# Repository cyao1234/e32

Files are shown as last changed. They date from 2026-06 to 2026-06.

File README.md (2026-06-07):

# ESP32-s2 development board

With drunk components!

---



This is a single board esp32-s2 development board. with two neopixels and an on-board antenna.

It has drunk component placement and some nice freeform traces

The 2.54mm pitch can be fitten in breadboard and used nicely with jumpers

The programming can be done over USB-C ports

---



The scehmatic is easy and simple, giving people the maximum leverage.

Everything is impedance matched, giving the best EMC and high-speed SI performance

---

For bom see `bom.csv`

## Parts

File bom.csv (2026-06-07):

What | $$$ | Where
PCB | $82.32 | JLCPCB
Components | $39.24 | lcsc

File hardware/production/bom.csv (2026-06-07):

Designator | Footprint | Quantity | Value | LCSC Part #
C1, C2 | 0402 | 2 | 33pF | C5137486
C10 | 0402 | 1 | 100nF | C1525
C3, C4, C5, C6, C7, C8, C9 | 0402 | 7 | 1uF | C52923
C39, C40 | 0402 | 2 | 4.7uF | C23733
D1, D2 | LED_WS2812B-2020_PLCC4_2.0x2.0mm | 2 | WS2812B-2020 | C5349955
F1 | 0805 | 1 | Fuse
J1 | USB_C_Receptacle_HRO_TYPE-C-31-M-12 | 1 | USB_C_Receptacle_USB2.0_14P | C165948
J5, J6 | PinHeader_1x15_P2.54mm_Vertical | 2 | Conn_01x15
R1, R2, R3, R4, R5 | 0402 | 5 | 5.1k | C25905
R6, R7, R8 | 0402 | 3 | 10k | C25744
SW1 | switch_button_TS-1088-AR02016 | 1 | SW_Push | C720477
U1 | QFN-56-1EP_7x7mm_P0.4mm_EP4x4mm_ThermalVias | 1 | ESP32-S2 | C2840995
U2 | SOT-23-3 | 1 | XC6206PxxxMR | C5446
Y1 | Crystal_SMD_2016-4Pin_2.0x1.6mm | 1 | 25MHz 20pF | C37635326

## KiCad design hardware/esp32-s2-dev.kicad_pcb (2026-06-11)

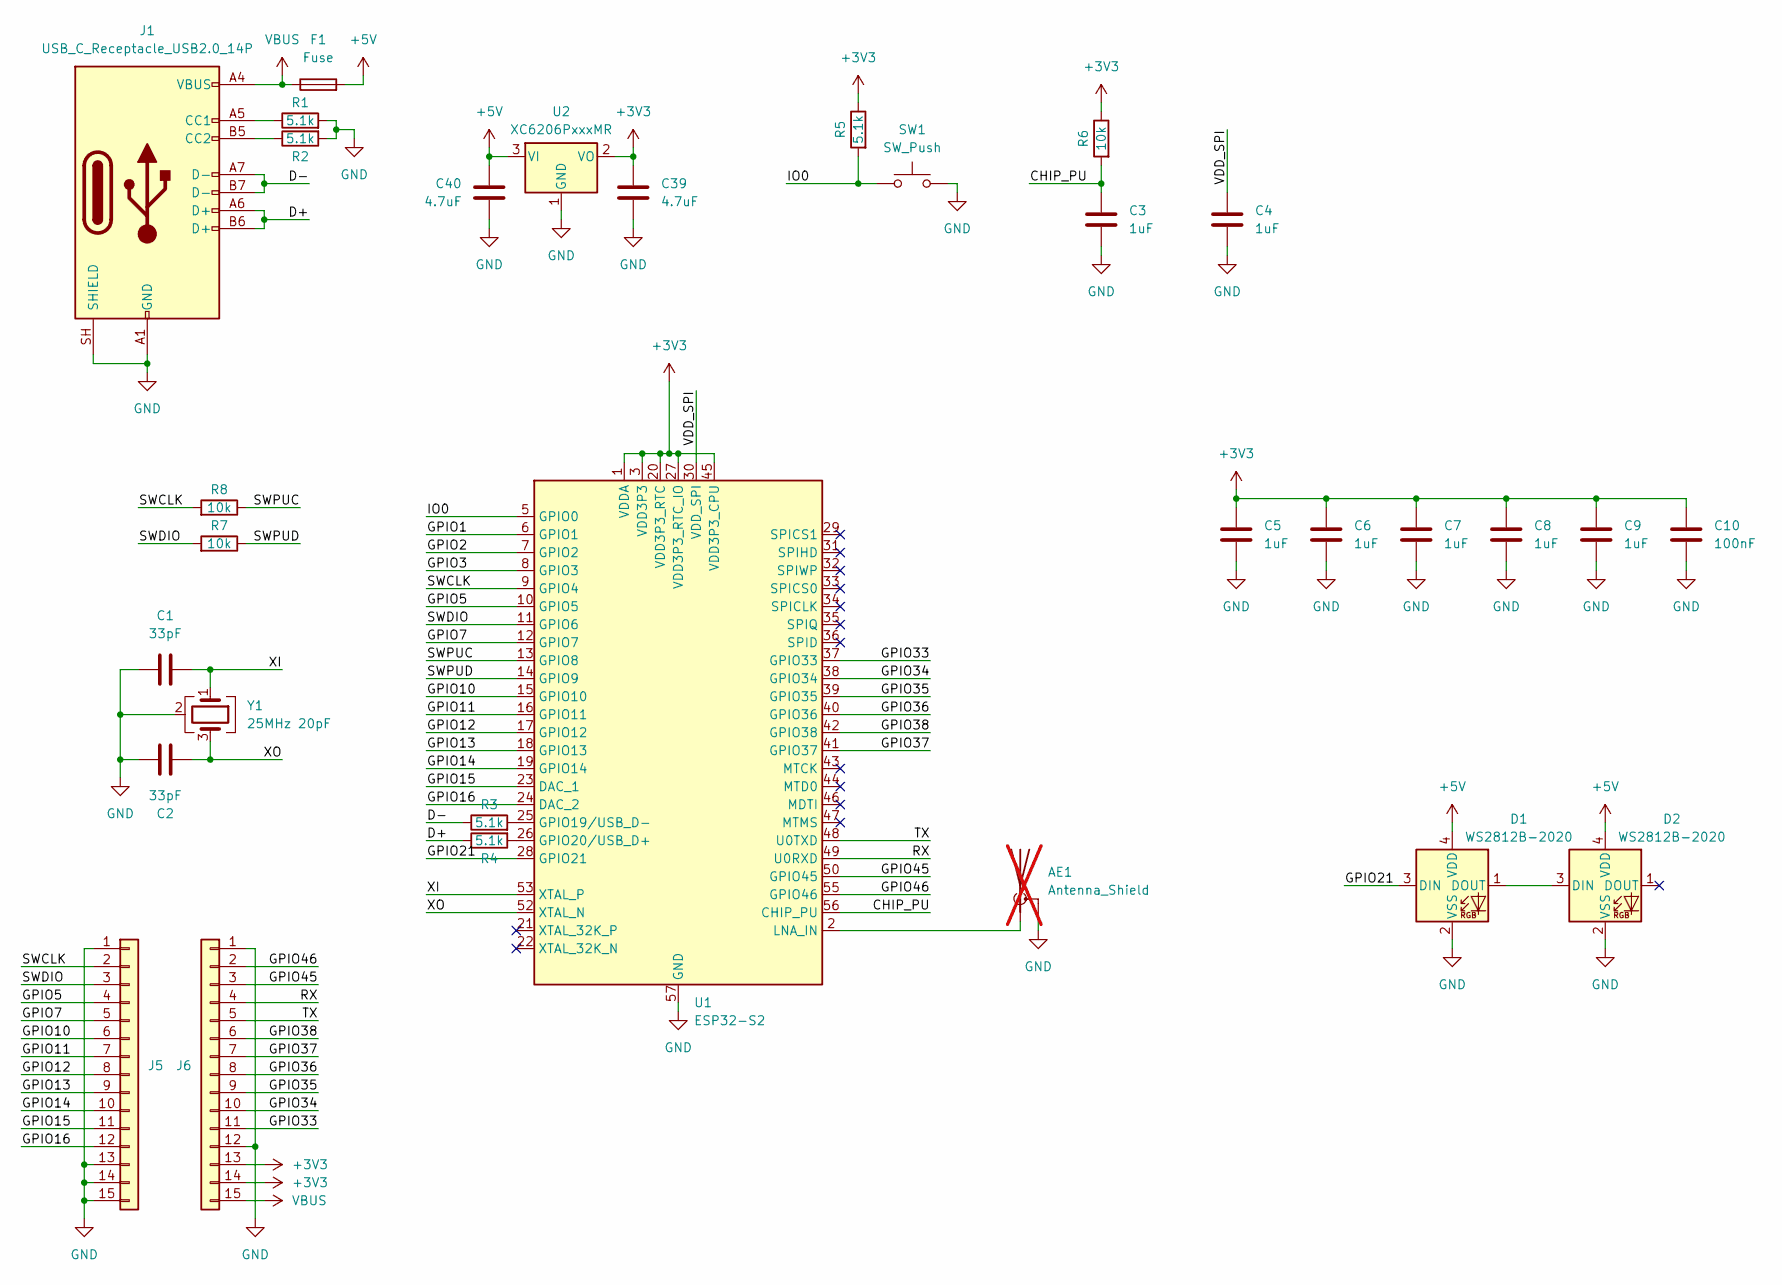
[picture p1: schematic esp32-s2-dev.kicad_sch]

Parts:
AE1: Antenna_Shield; Texas_SWRA117D_2.4GHz_Left; not fitted
C1, C2: 33pF; C_0402_1005Metric; LCSC Part # C5137486
C3, C4, C5, C6, C7, C8, C9: 1uF; C_0402_1005Metric; LCSC Part # C52923
C10: 100nF; C_0402_1005Metric; LCSC Part # C1525
C39, C40: 4.7uF; C_0402_1005Metric; LCSC Part # C23733
D1, D2: WS2812B-2020; LED_WS2812B-2020_PLCC4_2.0x2.0mm; LCSC Part # C5349955
F1: Fuse; Fuse_0805_2012Metric
J1: USB_C_Receptacle_USB2.0_14P; USB_C_Receptacle_HRO_TYPE-C-31-M-12; LCSC Part # C165948
J5, J6: Conn_01x15; PinHeader_1x15_P2.54mm_Vertical
R1, R2, R3, R4, R5: 5.1k; R_0402_1005Metric; LCSC Part # C25905
R6, R7, R8: 10k; R_0402_1005Metric; LCSC Part # C25744
SW1: SW_Push; switch_button_TS-1088-AR02016; LCSC Part # C720477
U1: ESP32-S2; QFN-56-1EP_7x7mm_P0.4mm_EP4x4mm_ThermalVias; LCSC Part # C2840995
U2: XC6206PxxxMR; SOT-23-3; LCSC Part # C5446
Y1: 25MHz 20pF; Crystal_SMD_2016-4Pin_2.0x1.6mm; LCSC Part # C37635326

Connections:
+3V3: C5.1, C6.1, C7.1, C8.1, C9.1, C10.1, C39.1, J6.13, J6.14, R5.1, R6.1, U1.1 (VDDA), U1.3 (VDD3P3), U1.4 (VDD3P3), U1.20 (VDD3P3_RTC), U1.27 (VDD3P3_RTC_IO), U1.45 (VDD3P3_CPU), U1.51 (VDDA), U1.54 (VDDA), U2.2 (VO)
+5V: C40.1, D1.4 (VDD), D2.4 (VDD), F1.2, U2.3 (VI)
/CHIP_PU: C3.1, R6.2, U1.56 (CHIP_PU)
/D+: J1.A6 (D+), J1.B6 (D+), R4.1
/D-: J1.A7 (D-), J1.B7 (D-), R3.1
/GPIO1: U1.6 (GPIO1)
/GPIO2: U1.7 (GPIO2)
/GPIO3: U1.8 (GPIO3)
/GPIO5: J5.4, U1.10 (GPIO5)
/GPIO7: J5.5, U1.12 (GPIO7)
/GPIO10: J5.6, U1.15 (GPIO10)
/GPIO11: J5.7, U1.16 (GPIO11)
/GPIO12: J5.8, U1.17 (GPIO12)
/GPIO13: J5.9, U1.18 (GPIO13)
/GPIO14: J5.10, U1.19 (GPIO14)
/GPIO15: J5.11, U1.23 (DAC_1)
/GPIO16: J5.12, U1.24 (DAC_2)
/GPIO21: D1.3 (DIN), U1.28 (GPIO21)
/GPIO33: J6.11, U1.37 (GPIO33)
/GPIO34: J6.10, U1.38 (GPIO34)
/GPIO35: J6.9, U1.39 (GPIO35)
/GPIO36: J6.8, U1.40 (GPIO36)
/GPIO37: J6.7, U1.41 (GPIO37)
/GPIO38: J6.6, U1.42 (GPIO38)
/GPIO45: J6.3, U1.50 (GPIO45)
/GPIO46: J6.2, U1.55 (GPIO46)
/IO0: R5.2, SW1.1, U1.5 (GPIO0)
/RX: J6.4, U1.49 (U0RXD)
/SWCLK: J5.2, R8.2, U1.9 (GPIO4)
/SWDIO: J5.3, R7.2, U1.11 (GPIO6)
/SWPUC: R8.1, U1.13 (GPIO8)
/SWPUD: R7.1, U1.14 (GPIO9)
/TX: J6.5, U1.48 (U0TXD)
/VDD_SPI: C4.1, U1.30 (VDD_SPI)
/XI: C1.2, U1.53 (XTAL_P), Y1.1
/XO: C2.2, U1.52 (XTAL_N), Y1.3
GND: AE1.2 (Shield), C1.1, C2.1, C3.2, C4.2, C5.2, C6.2, C7.2, C8.2, C9.2, C10.2, C39.2, C40.2, D1.2 (VSS), D2.2 (VSS), J1.A1 (GND), J1.A12 (GND), J1.B1 (GND), J1.B12 (GND), J1.SH (SHIELD), J5.1, J5.13, J5.14, J5.15, J6.1, J6.12, R1.2, R2.2, SW1.2, U1.57 (GND), U2.1 (GND), Y1.2 (G), Y1.4 (G)
unnamed: AE1.1 (A), U1.2 (LNA_IN)
unnamed: D1.1 (DOUT), D2.3 (DIN)
unnamed: J1.A5 (CC1), R1.1
unnamed: J1.B5 (CC2), R2.1
unnamed: R3.2, U1.25 (GPIO19/USB_D-)
unnamed: R4.2, U1.26 (GPIO20/USB_D+)
VBUS: F1.1, J1.A4 (VBUS), J1.A9 (VBUS), J1.B4 (VBUS), J1.B9 (VBUS), J6.15

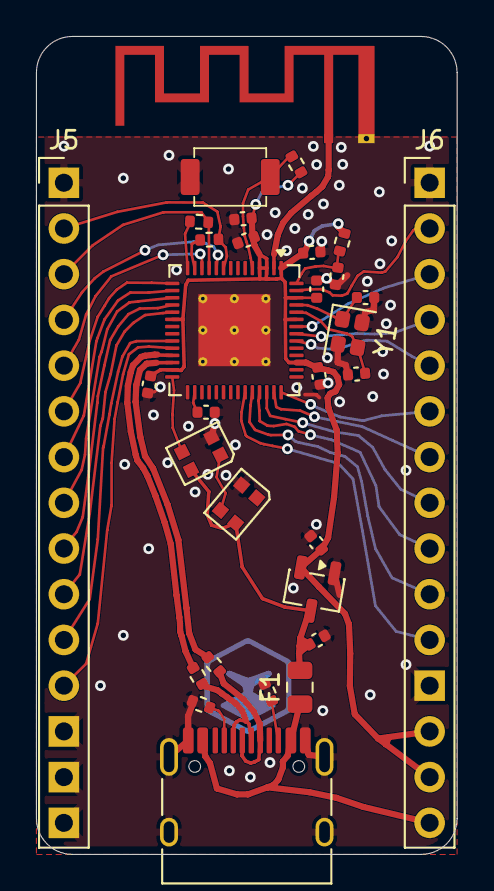
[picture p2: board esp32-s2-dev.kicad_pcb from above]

Board: 2 copper layers, 23.4 x 45.4 mm, 32 parts (1 on the bottom side), 41 nets.

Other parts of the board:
H2: MountingHole; Icy Electronics Logo
